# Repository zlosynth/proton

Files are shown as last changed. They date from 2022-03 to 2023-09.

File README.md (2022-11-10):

# Proton

Playground module for eurorack prototyping.

<p align="center">
   Panel illustration
</p>

* This is meant to help to test ideas of new modules before they get their own
  custom hardware.
* This is not meant to be stable or simple.

# Development

See [DEVELOPMENT.md](DEVELOPMENT.md) to find some basic commands to interact
with the project.

# License

Software of Proton is distributed under the terms of the General Public
License version 3. See [LICENSE-SOFTWARE](LICENSE-SOFTWARE) for details.

Schematics and PCB layout are distributed under the terms of Creative Commons
BY-SA. See [LICENSE-HARDWARE](LICENSE-HARDWARE) for details. Parts of the
schematics are based on [Emilie Gillet's Mutable
Instruments](https://github.com/pichenettes/eurorack) and [Electrosmith's
Patch](https://www.electro-smith.com/daisy/patch) kudos to them for making them
open.

# Changelog

Read the [CHANGELOG.md](CHANGELOG.md) to learn about changes introduced in each
release.

# Versioning

See [VERSIONING.md](VERSIONING.md) to find detailed information about versioning
of the project and compatability between its software and hardware.

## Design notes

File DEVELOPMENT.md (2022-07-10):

# Development

## Environment setup

Follow [Rust's installation guide](https://www.rust-lang.org/tools/install).

Install tooling of the embedded Rust target for Cortex-M7F:

```sh
rustup target add thumbv7em-none-eabihf
```

## Formatting, linting, unit tests

Run formatting, linter and unit tests:

```sh
make
```

Read the Makefile to learn more.

## Benchmark

If a package has a benchmark defined, `cd` into its directory and run it via:

``` sh
cargo +nightly bench --bench bench
```

Use the benchmark for profiling:

``` sh
rm -f target/release/deps/bench-*
rm -f callgrind.out.*
RUSTFLAGS="-g" cargo +nightly bench --bench bench --no-run
BENCH=$(find target/release/deps -type f -executable -name 'bench-*')
TEST=instrument
valgrind \
    --tool=callgrind \
    --dump-instr=yes \
    --collect-jumps=yes \
    --simulate-cache=yes \
    ${BENCH} --bench --profile-time 10 ${TEST}
kcachegrind callgrind.out.*
```

## Flash via ST-Link

This requires external probe, such as the ST LINK-V3 MINI. The benefit of this
approach is that it allows to stay connected to the module, read logs, run a
debugger, or execute tests on the module. Note that the module needs to be
powered while the probe is connected.

This project uses [probe-rs](https://github.com/probe-rs/probe-rs) to deal with
flashing. Start by installing its dependencies. For Fedora, it can be done by
running the following:

```sh
sudo dnf install -y libusbx-devel libftdi-devel libudev-devel
```

You may then install needed udev rules. See the [probe-rs getting
started](https://probe.rs/docs/getting-started/probe-setup/) to learn how.

Then install Rust dependencies of probe-rs:

```sh
cargo install probe-run
cargo install flip-link
```

To flash the project, call this make target:

```sh
make flash
```

Logging level can be set using an environment variable:

```sh
DEFMT_LOG=info make flash
```

To flash a release build, set a flag:

```sh
make flash FLAGS="--release"
```

Some tests must be executed directly on the module. To run those, use the
following target:

```sh
make test-embedded
```

## Flash via DFU

Unlike ST-Link, DFU flashing does not require any external probe. Just connect
the module to your computer via a USB cable.

First, install [dfu-util](http://dfu-util.sourceforge.net/). On Fedora, this can
be done by calling:

```sh
sudo dnf install dfu-util
```

To flash the project, call this make target:

```sh
make flash-dfu
```

To flash a release build, extend the command with a flag:

```sh
make flash-dfu FLAGS="--release"
```

## Firmware size

Check firmware size:

```sh
cd eurorack && cargo +nightly size --bin firmware --release -- -m # or -A
```

## Run a debugger

I prefer to use [gdbgui](https://www.gdbgui.com/) when I need to attach a
debugger to a test run.

First, install gdbgui following its [installation
guide](https://www.gdbgui.com/installation/). The make target also requires `jq`
to be installed in the system.

To attach the debugger to a unit test run:

```sh
make debug-test WHAT=ui
```

After the debugger is open, set breakpoints, type `r` into the GDB console and
click Continue.

## Pure data

To try out the project via Pure Data:

```sh
make puredata
```

And more under `hack/` and in the `Makefile`.

## Gerbers, BOM and CPL

I extensivelly use https://github.com/Bouni/kicad-jlcpcb-tools to deal with the
matters listed in the title, and to prepare project for manufacture.

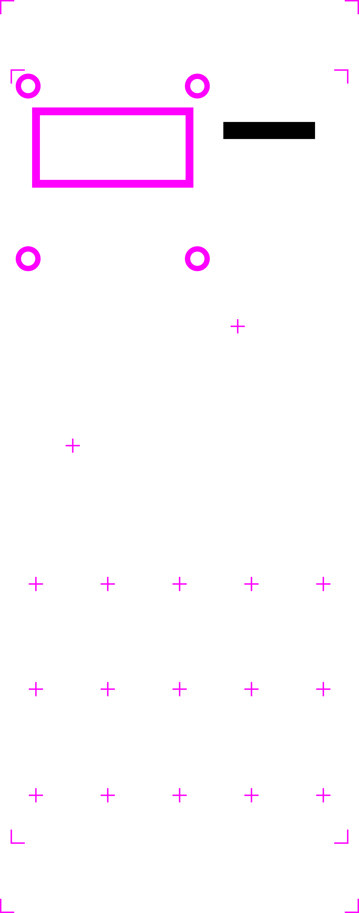
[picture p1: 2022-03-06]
hardware/outlines.png

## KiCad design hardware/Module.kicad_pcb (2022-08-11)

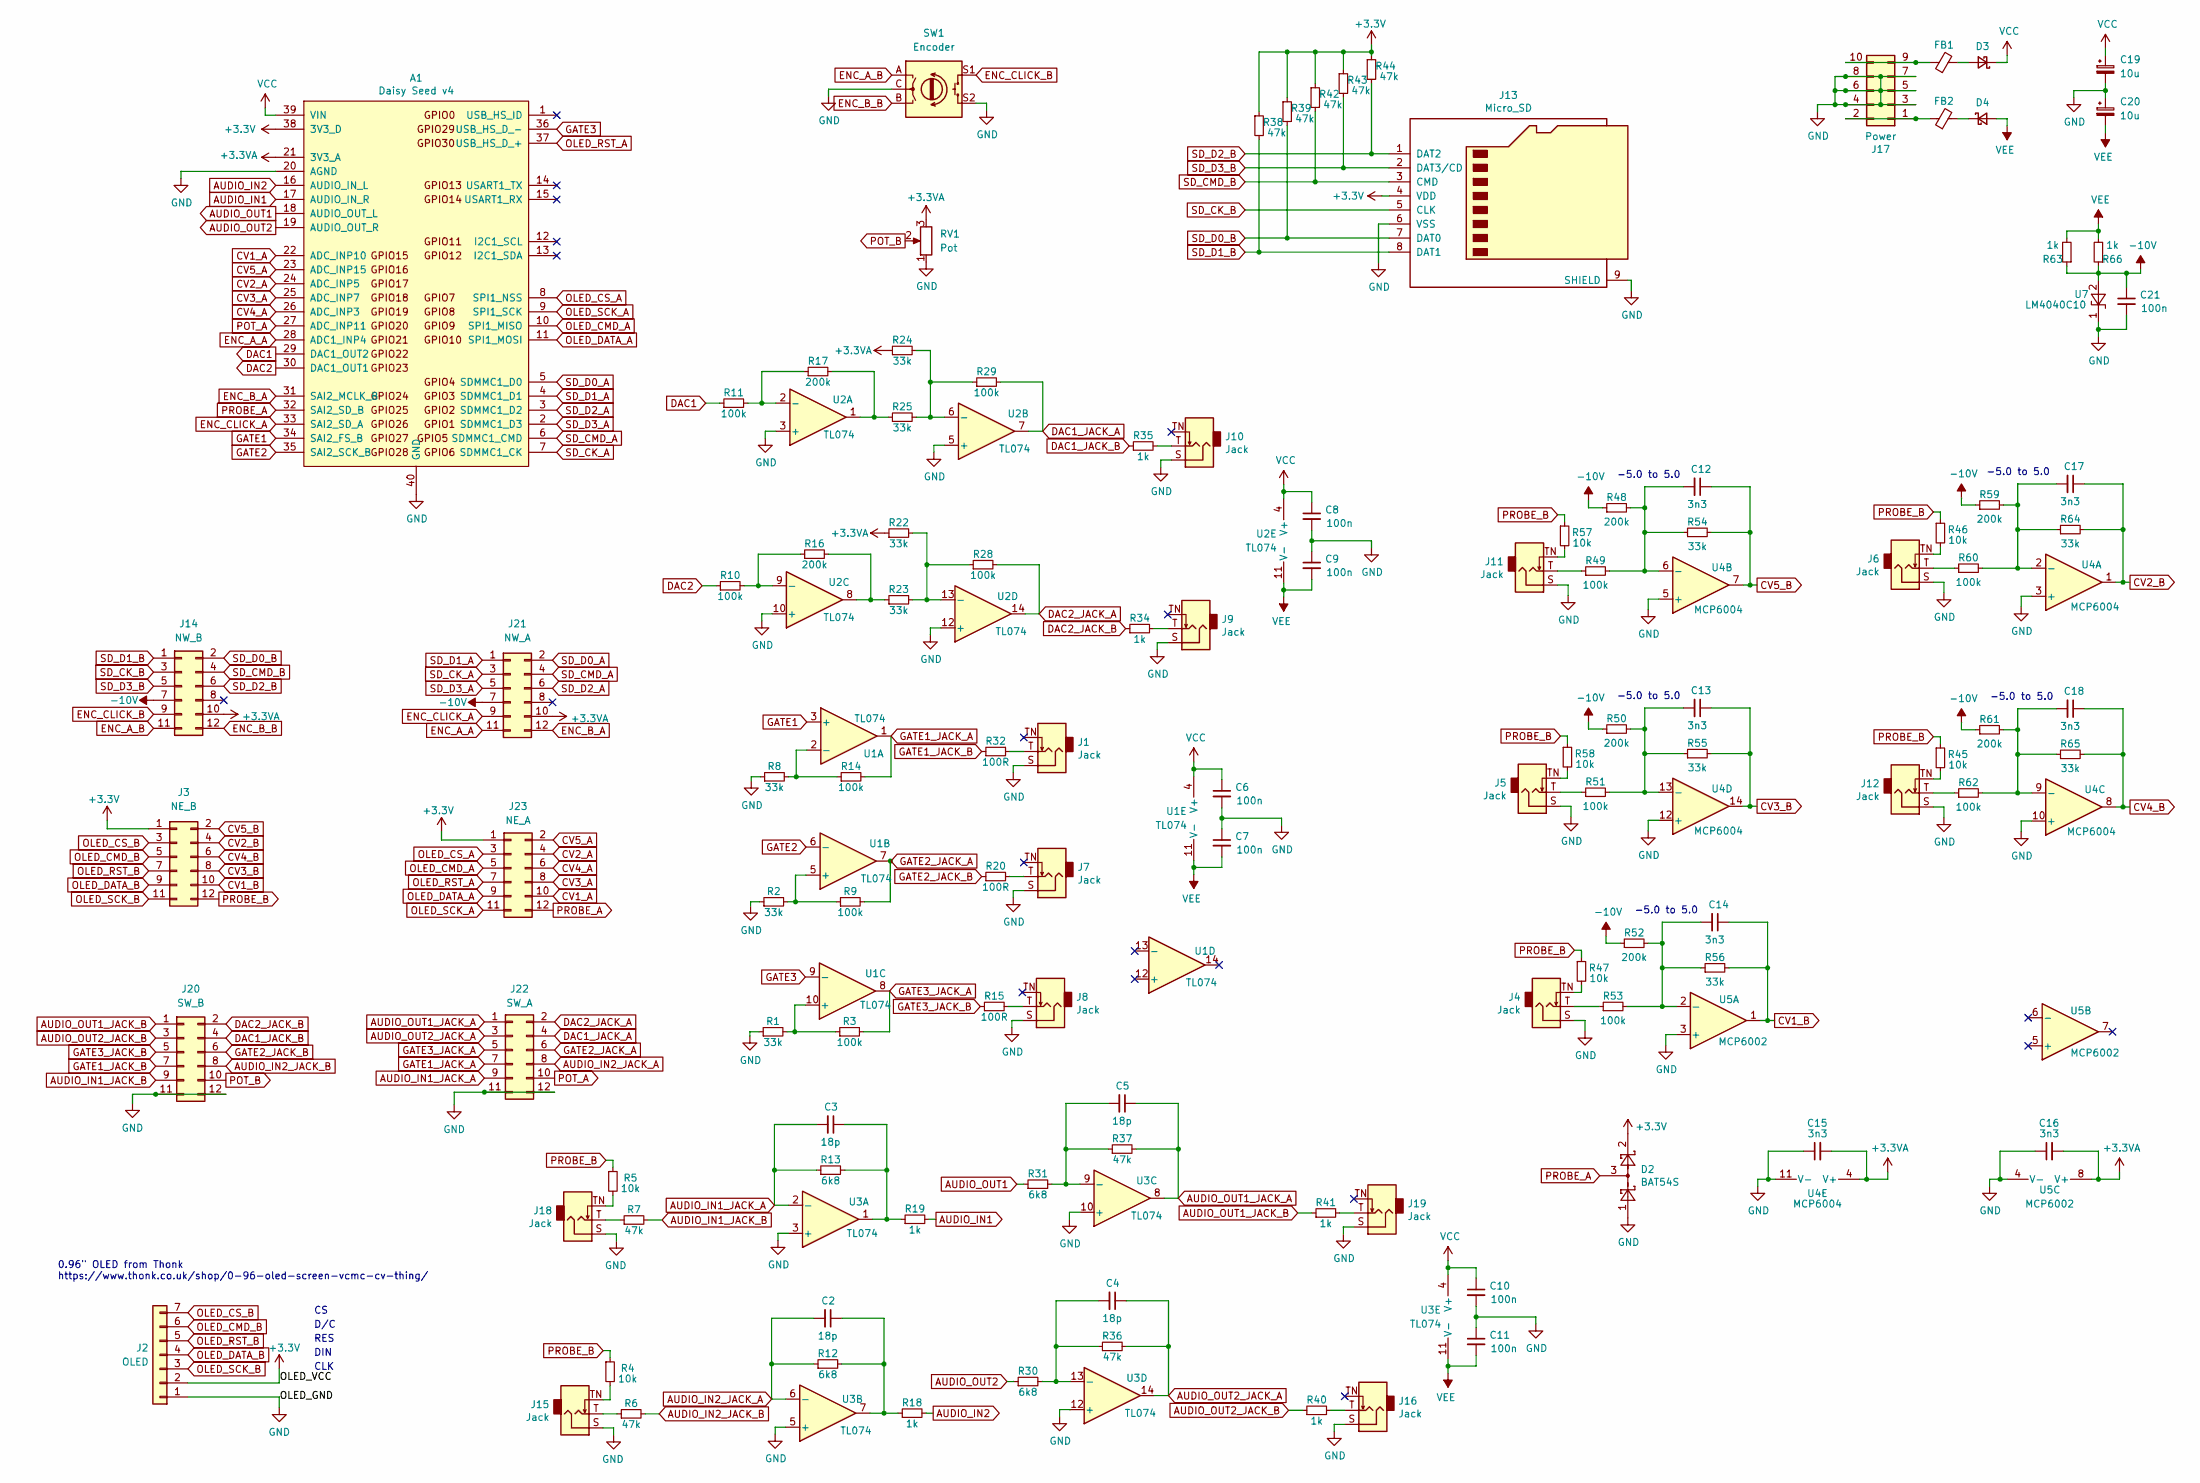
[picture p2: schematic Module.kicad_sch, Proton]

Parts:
A1: Daisy Seed v4; Device_Audio_Electrosmith_Daisy_Seed; Mfr Part Number M20-7822046
C2, C3, C4, C5: 18p; C_0603_1608Metric_Pad1.08x0.95mm_HandSolder; Mfr Part Number CL10C180JB81PNC; LCSC C1647
C6, C7, C8, C9, C10, C11: 100n; C_0603_1608Metric_Pad1.08x0.95mm_HandSolder; Mfr Part Number CL10F104ZO8NNNC; LCSC C14663
C12, C13, C14, C15, C16, C17, C18: 3n3; C_0603_1608Metric_Pad1.08x0.95mm_HandSolder; Mfr Part Number CL10B332KB8NNNC; LCSC C1613
C19, C20: 10u; CP_Elec_6.3x5.8
C21: 100n; C_0603_1608Metric_Pad1.08x0.95mm_HandSolder; Mfr Part Number CL31B104KBCNNNL; LCSC C24497
D2: BAT54S; SOT-23_Handsoldering; Mfr Part Number BAT54S,215
D3, D4: Schottky; D_SOD-123; Mfr Part Number STPS0540ZY; LCSC C8598
FB1, FB2: FB; L_0603_1608Metric_Pad1.05x0.95mm_HandSolder
J1, J4, J5, J6, J7, J8, J9, J10, J11, J12, J15, J16, J18, J19: Jack; Jack_3.5mm_QingPu_WQP-PJ398SM_Vertical_CircularHoles
J2: OLED; PinSocket_1x07_P2.54mm_Vertical
J3: NE_B; PinSocket_2x06_P2.54mm_Vertical
J13: Micro_SD; microsd_connector
J14: NW_B; PinSocket_2x06_P2.54mm_Vertical
J17: Power; PinHeader_2x05_P2.54mm_Vertical; Mfr Part Number 87914-1016
J20: SW_B; PinSocket_2x06_P2.54mm_Vertical
J21: NW_A; PinHeader_2x06_P2.54mm_Vertical
J22: SW_A; PinHeader_2x06_P2.54mm_Vertical
J23: NE_A; PinHeader_2x06_P2.54mm_Vertical
R1, R2, R8, R22, R23, R24, R25: 33k; R_0603_1608Metric_Pad0.98x0.95mm_HandSolder; Mfr Part Number CR0603-JW-682ELF; LCSC C23212
R3, R9, R14, R28, R29: 100k; R_0603_1608Metric_Pad0.98x0.95mm_HandSolder; Mfr Part Number CR0603-FX-4702ELF; LCSC C25819
R4, R5, R45, R46, R47, R57, R58: 10k; R_0603_1608Metric_Pad0.98x0.95mm_HandSolder; Mfr Part Number CR0603-FX-1002ELF; LCSC C25744
R6, R7: 47k; R_0603_1608Metric_Pad0.98x0.95mm_HandSolder; Mfr Part Number CR0603-JW-682ELF; LCSC C23212
R10, R11: 100k; R_0603_1608Metric_Pad0.98x0.95mm_HandSolder; Mfr Part Number CR0603-JW-682ELF; LCSC C23212
R12, R13: 6k8; R_0603_1608Metric_Pad0.98x0.95mm_HandSolder; Mfr Part Number CR0603-FX-4702ELF; LCSC C25819
R15, R20, R32: 100R; R_0603_1608Metric_Pad0.98x0.95mm_HandSolder; Mfr Part Number CR0603-FX-1001ELF; LCSC C21190
R16, R17: 200k; R_0603_1608Metric_Pad0.98x0.95mm_HandSolder; Mfr Part Number CR0603-FX-4702ELF; LCSC C25819
R18, R19, R34, R35, R40, R41, R63, R66: 1k; R_0603_1608Metric_Pad0.98x0.95mm_HandSolder; Mfr Part Number CR0603-FX-1001ELF; LCSC C21190
R30, R31: 6k8; R_0603_1608Metric_Pad0.98x0.95mm_HandSolder; Mfr Part Number CR0603-JW-682ELF; LCSC C23212
R36, R37: 47k; R_0603_1608Metric_Pad0.98x0.95mm_HandSolder; Mfr Part Number CR0603-FX-4702ELF; LCSC C25819
R38, R39, R42, R43, R44: 47k; R_0603_1608Metric_Pad0.98x0.95mm_HandSolder; Mfr Part Number CR0603-FX-1002ELF; LCSC C25744
R48: 200k; R_0603_1608Metric_Pad0.98x0.95mm_HandSolder; Mfr Part Number CR0603-FX-1803ELF; LCSC C25808
R49, R51, R53, R60, R62: 100k; R_0603_1608Metric_Pad0.98x0.95mm_HandSolder; Mfr Part Number CR0603-JW-104ELF; LCSC C25803
R50: 200k; R_0603_1608Metric_Pad0.98x0.95mm_HandSolder; Mfr Part Number CR0603-FX-1203ELF; LCSC C22827
R52, R61: 200k; R_0603_1608Metric_Pad0.98x0.95mm_HandSolder; Mfr Part Number CR0603-FX-1203ELF; LCSC C25808
R54: 33k; R_0603_1608Metric_Pad0.98x0.95mm_HandSolder; Mfr Part Number CR0603-FX-4702ELF; LCSC C4184
R55: 33k; R_0603_1608Metric_Pad0.98x0.95mm_HandSolder; Mfr Part Number CR0603-FX-2002ELF; LCSC C25819
R56, R65: 33k; R_0603_1608Metric_Pad0.98x0.95mm_HandSolder; Mfr Part Number CR0603-FX-2002ELF; LCSC C4184
R59: 200k; R_0603_1608Metric_Pad0.98x0.95mm_HandSolder; Mfr Part Number CR0603-FX-1803ELF; LCSC C22827
R64: 33k; R_0603_1608Metric_Pad0.98x0.95mm_HandSolder; Mfr Part Number CR0603-FX-4702ELF; LCSC C25819
RV1: Pot; Potentiometer_Alpha_RD901F-40-00D_Single_Vertical
SW1: Encoder; RotaryEncoder_Alps_EC11E-Switch_Vertical_H20mm
U1, U2, U3: TL074; SOIC-14_3.9x8.7mm_P1.27mm
U4: MCP6004; SOIC-14_3.9x8.7mm_P1.27mm
U5: MCP6002; SOIC-8_3.9x4.9mm_P1.27mm; Mfr Part Number MCP6002-I/SN; LCSC C7377
U7: LM4040C10; SOT-23_Handsoldering; Mfr Part Number LM4040C10IDBZR; LCSC C201738

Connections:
+3.3VA: A1.21 (3V3_A), C15.2, C16.2, J14.10, J21.10, R22.1, R24.1, RV1.3, U4.4 (V+), U5.8 (V+)
+3V3: A1.38 (3V3_D), D2.2, J2.2, J3.1, J13.4 (VDD), J23.1, R38.1, R39.1, R42.1, R43.1, R44.1
-10V: C21.1, J14.7, J21.7, R48.1, R50.1, R52.1, R59.1, R61.1, R63.1, R66.1, U7.2 (A)
AUDIO_IN1: A1.17 (AUDIO_IN_R), R19.2
AUDIO_IN1_JACK_A: C3.2, J22.9, R13.1, U3.2 (-)
AUDIO_IN1_JACK_B: J20.9, R7.2
AUDIO_IN2: A1.16 (AUDIO_IN_L), R18.2
AUDIO_IN2_JACK_A: C2.2, J22.8, R12.1, U3.6 (-)
AUDIO_IN2_JACK_B: J20.8, R6.2
AUDIO_OUT1: A1.18 (AUDIO_OUT_L), R31.1
AUDIO_OUT1_JACK_A: C5.1, J22.1, R37.2, U3.8
AUDIO_OUT1_JACK_B: J20.1, R41.1
AUDIO_OUT2: A1.19 (AUDIO_OUT_R), R30.1
AUDIO_OUT2_JACK_A: C4.1, J22.3, R36.2, U3.14
AUDIO_OUT2_JACK_B: J20.3, R40.1
CV1_A: A1.22 (ADC_INP10), J23.10
CV1_B: C14.1, J3.10, R56.2, U5.1
CV2_A: A1.24 (ADC_INP5), J23.4
CV2_B: C17.1, J3.4, R64.2, U4.1
CV3_A: A1.25 (ADC_INP7), J23.8
CV3_B: C13.1, J3.8, R55.2, U4.14
CV4_A: A1.26 (ADC_INP3), J23.6
CV4_B: C18.1, J3.6, R65.2, U4.8
CV5_A: A1.23 (ADC_INP15), J23.2
CV5_B: C12.1, J3.2, R54.2, U4.7
DAC1: A1.29 (DAC1_OUT2), R11.1
DAC1_JACK_A: J22.4, R29.2, U2.7
DAC1_JACK_B: J20.4, R35.1
DAC2: A1.30 (DAC1_OUT1), R10.1
DAC2_JACK_A: J22.2, R28.2, U2.14
DAC2_JACK_B: J20.2, R34.1
ENC_A_A: A1.28 (ADC1_INP4), J21.11
ENC_A_B: J14.11, SW1.A
ENC_B_A: A1.31 (SAI2_MCLK_B), J21.12
ENC_B_B: J14.12, SW1.B
ENC_CLICK_A: A1.33 (SAI2_SD_A), J21.9
ENC_CLICK_B: J14.9, SW1.S1
GATE1: A1.34 (SAI2_FS_B), U1.3 (+)
GATE1_JACK_A: J22.7, R14.2, U1.1
GATE1_JACK_B: J20.7, R32.1
GATE2: A1.35 (SAI2_SCK_B), U1.6 (-)
GATE2_JACK_A: J22.6, R9.2, U1.7
GATE2_JACK_B: J20.6, R20.1
GATE3: A1.36 (USB_HS_D_-), U1.9 (-)
GATE3_JACK_A: J22.5, R3.2, U1.8
GATE3_JACK_B: J20.5, R15.1
GND: A1.20 (AGND), A1.40 (GND), C6.2, C7.1, C8.2, C9.1, C10.2, C11.1, C15.1, C16.1, C19.2, C20.1, C21.2, D2.1, J1.S, J2.1, J4.S, J5.S, J6.S, J7.S, J8.S, J9.S, J10.S, J11.S, J12.S, J13.6 (VSS), J13.9 (SHIELD), J15.S, J16.S, J17.3, J17.4, J17.5, J17.6, J17.7, J17.8, J18.S, J19.S, J20.11, J20.12, J22.11, J22.12, R1.1, R2.1, R8.1, RV1.1, SW1.C, SW1.S2, U2.3 (+), U2.5 (+), U2.10 (+), U2.12 (+), U3.3 (+), U3.5 (+), U3.10 (+), U3.12 (+), U4.3 (+), U4.5 (+), U4.10 (+), U4.11 (V-), U4.12 (+), U5.3 (+), U5.4 (V-), U7.1 (K)
unnamed: C2.1, R12.2, R18.1, U3.7
unnamed: C3.1, R13.2, R19.1, U3.1
unnamed: C4.2, R30.2, R36.1, U3.13 (-)
unnamed: C5.2, R31.2, R37.1, U3.9 (-)
unnamed: C12.2, R48.2, R49.2, R54.1, U4.6 (-)
unnamed: C13.2, R50.2, R51.2, R55.1, U4.13 (-)
unnamed: C14.2, R52.2, R53.2, R56.1, U5.2 (-)
unnamed: C17.2, R59.2, R60.2, R64.1, U4.2 (-)
unnamed: C18.2, R61.2, R62.2, R65.1, U4.9 (-)
unnamed: D3.2 (A), FB1.2
unnamed: D4.1 (K), FB2.2
unnamed: FB1.1, J17.9, J17.10
unnamed: FB2.1, J17.1, J17.2
unnamed: J1.T, R32.2
unnamed: J4.T, R53.1
unnamed: J4.TN, R47.2
unnamed: J5.T, R51.1
unnamed: J5.TN, R58.2
unnamed: J6.T, R60.1
unnamed: J6.TN, R46.2
unnamed: J7.T, R20.2
unnamed: J8.T, R15.2
unnamed: J9.T, R34.2
unnamed: J10.T, R35.2
unnamed: J11.T, R49.1
unnamed: J11.TN, R57.2
unnamed: J12.T, R62.1
unnamed: J12.TN, R45.2
unnamed: J15.T, R6.1
unnamed: J15.TN, R4.2
unnamed: J16.T, R40.2
unnamed: J18.T, R7.1
unnamed: J18.TN, R5.2
unnamed: J19.T, R41.2
unnamed: R1.2, R3.1, U1.10 (+)
unnamed: R2.2, R9.1, U1.5 (+)
unnamed: R10.2, R16.1, U2.9 (-)
unnamed: R11.2, R17.1, U2.2 (-)
unnamed: R8.2, R14.1, U1.2 (-)
unnamed: R16.2, R23.1, U2.8
unnamed: R17.2, R25.1, U2.1
unnamed: R22.2, R23.2, R28.1, U2.13 (-)
unnamed: R24.2, R25.2, R29.1, U2.6 (-)
OLED_CMD_A: A1.10 (SPI1_MISO), J23.5
OLED_CMD_B: J2.6, J3.5
OLED_CS_A: A1.8 (SPI1_NSS), J23.3
OLED_CS_B: J2.7, J3.3
OLED_DATA_A: A1.11 (SPI1_MOSI), J23.9
OLED_DATA_B: J2.4, J3.9
OLED_RST_A: A1.37 (USB_HS_D_+), J23.7
OLED_RST_B: J2.5, J3.7
OLED_SCK_A: A1.9 (SPI1_SCK), J23.11
OLED_SCK_B: J2.3, J3.11
POT_A: A1.27 (ADC_INP11), J22.10
POT_B: J20.10, RV1.2
PROBE_A: A1.32 (SAI2_SD_B), D2.3, J23.12
PROBE_B: J3.12, R4.1, R5.1, R45.1, R46.1, R47.1, R57.1, R58.1
SD_CK_A: A1.7 (SDMMC1_CK), J21.3
SD_CK_B: J13.5 (CLK), J14.3
SD_CMD_A: A1.6 (SDMMC1_CMD), J21.4
SD_CMD_B: J13.3 (CMD), J14.4, R42.2
SD_D0_A: A1.5 (SDMMC1_D0), J21.2
SD_D0_B: J13.7 (DAT0), J14.2, R39.2
SD_D1_A: A1.4 (SDMMC1_D1), J21.1
SD_D1_B: J13.8 (DAT1), J14.1, R38.2
SD_D2_A: A1.3 (SDMMC1_D2), J21.6
SD_D2_B: J13.1 (DAT2), J14.6, R44.2
SD_D3_A: A1.2 (SDMMC1_D3), J21.5
SD_D3_B: J13.2 (DAT3/CD), J14.5, R43.2
VCC: A1.39 (VIN), C6.1, C8.1, C10.1, C19.1, D3.1 (K), U1.4 (V+), U2.4 (V+), U3.4 (V+)
VEE: C7.2, C9.2, C11.2, C20.2, D4.2 (A), R63.2, R66.2, U1.11 (V-), U2.11 (V-), U3.11 (V-)

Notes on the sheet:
-5.0 to 5.0
0.96" OLED from Thonk https://www.thonk.co.uk/shop/0-96-oled-screen-vcmc-cv-thing/
CLK
RES
DIN
D/C

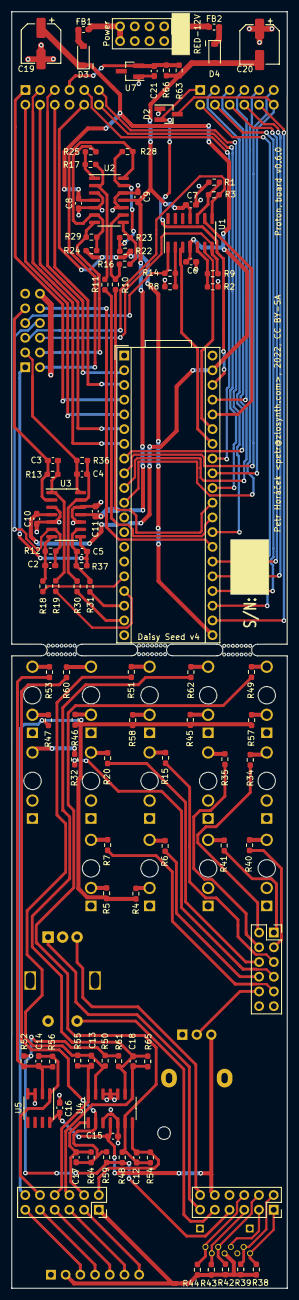
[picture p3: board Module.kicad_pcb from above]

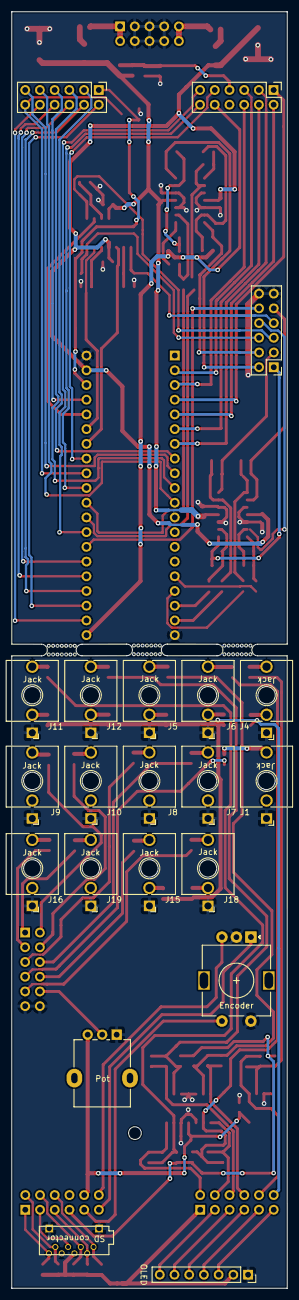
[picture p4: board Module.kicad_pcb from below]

Board: 2 copper layers, 47.6 x 220.4 mm, 122 parts (21 on the bottom side), 118 nets.

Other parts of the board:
mouse-bite-2mm-slot, mouse-bite-2mm-slot#2, mouse-bite-2mm-slot#3: VAL**; mouse-bite-2mm-slot

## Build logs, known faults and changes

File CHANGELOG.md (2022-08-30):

# Changelog

All notable changes to this project will be documented in this file. See
[VERSIONING.md](VERSIONING.md) for more information about versioning and
backwards compatibility.

## Unreleased

* Known issue: Gate 2 and 3 have reversed output of -10 V.
* Replace one of the encoders with a pot.
* Adjust encoder abstraction to the new hardware.
* Implement gate output.
* Implement CV output.
* Introduce binding to Kaseta.
* Process input audio.
* Remove global allocator.
* Remove karplus strong.
* Switch to stable Rust.

## 0.6.0

* Transform the module into two-board design.
* Remove MIDI input and output.
* Implement a basic tape simulation instrument.
* Introduce oversampling converters over the Signal trait.
* Reconcile CV inputs and pass them to instruments.
* Allow control of cutoff and feedback of karplus strong via CV.

## 0.5.0

* Implement sound output in the firmware.
* Introduce a basic instrument based around Karplus Strong algorithm.
* Allow custom settings for f32 attribute range.
* Implement a simple turing machine-like sequencer.

## 0.4.0

* Integrate display in the firmware.
* Use left encoder to move through attributes.
* Use right encoder to adjust attributes.

## 0.3.0

* Introduce support for module instantiation and removal.
* Implement menu for dynamic connecting and disconnecting of patches.

## 0.2.0

* Introduce signal buffer abstraction.
* Abstract cells used to access internal audio output and control input data.
* Implement read-only UI for 128x64 OLED displays.

## 0.1.0

* Initialize the project with READMEs and licensing.
* Add schetch of the front panel.
* Prepare schematics of the module.
* Design the PCB of the module.
* Implement basic saw oscillator.
* Introduce pure data external for testing.

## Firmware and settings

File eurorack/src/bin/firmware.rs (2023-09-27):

#![no_main]
#![no_std]

use proton_eurorack as _; // global logger + panicking-behavior

#[rtic::app(device = stm32h7xx_hal::pac, peripherals = true, dispatchers = [EXTI0, EXTI1, EXTI2])]
mod app {
    use core::mem::MaybeUninit;

    use fugit::ExtU64;
    use heapless::spsc::{Consumer, Producer, Queue};
    use systick_monotonic::Systick;

    use daisy::led::LedUser;
    use hal::adc::{Adc, Enabled};
    use hal::pac::{ADC1, ADC2};
    use stm32h7xx_hal as hal;

    #[cfg(feature = "traky")]
    use proton_instruments_traky::Instrument;

    use proton_control::input_snapshot::InputSnapshot;
    use proton_eurorack::system::audio::{Audio, SAMPLE_RATE};
    use proton_eurorack::system::display::Display;
    use proton_eurorack::system::randomizer::Randomizer;
    use proton_eurorack::system::System;
    use proton_instruments_interface::{Instrument as _, MemoryManager};
    use proton_ui::action::Action as InputAction;
    use proton_ui::display::draw as draw_view_on_display;
    use proton_ui::reaction::Reaction as InputReaction;
    use proton_ui::reducer;
    use proton_ui::state::State;
    use proton_ui::view::View;

    type UserInput = proton_ui::input::Input<
        proton_eurorack::system::encoder::EncoderRotaryPinA,
        proton_eurorack::system::encoder::EncoderRotaryPinB,
        proton_eurorack::system::encoder::EncoderButtonPin,
    >;

    type ControlInput = proton_control::input_processor::InputProcessor<
        Adc<ADC1, Enabled>,
        Adc<ADC2, Enabled>,
        proton_eurorack::system::cv_input::Pot,
        proton_eurorack::system::cv_input::CvInput1,
        proton_eurorack::system::cv_input::CvInput2,
        proton_eurorack::system::cv_input::CvInput3,
        proton_eurorack::system::cv_input::CvInput4,
        proton_eurorack::system::cv_input::CvInput5,
    >;

    type ControlOutput = proton_control::output_processor::OutputProcessor<
        proton_eurorack::system::gate_output::GateOutput1,
        proton_eurorack::system::gate_output::GateOutput2,
        proton_eurorack::system::gate_output::GateOutput3,
        proton_eurorack::system::cv_output::CvOutput1,
        proton_eurorack::system::cv_output::CvOutput2,
    >;

    #[monotonic(binds = SysTick, default = true)]
    type Mono = Systick<1000>; // 1 kHz / 1 ms granularity

    #[shared]
    struct Shared {}

    #[local]
    struct Local {
        audio: Audio,
        randomizer: Randomizer,
        instrument: Instrument,
        led: LedUser,
        user_input: UserInput,
        control_input: ControlInput,
        _control_output: ControlOutput,
        display: Display,
        state: State,
        input_actions_producer: Producer<'static, InputAction, 6>,
        input_actions_consumer: Consumer<'static, InputAction, 6>,
        input_reactions_producer: Producer<'static, InputReaction, 6>,
        input_reactions_consumer: Consumer<'static, InputReaction, 6>,
        control_input_producer: Producer<'static, InputSnapshot, 6>,
        control_input_consumer: Consumer<'static, InputSnapshot, 6>,
    }

    #[init(
        local = [
            input_actions_queue: Queue<InputAction, 6> = Queue::new(),
            input_reactions_queue: Queue<InputReaction, 6> = Queue::new(),
            control_input_queue: Queue<InputSnapshot, 6> = Queue::new(),
        ]
    )]
    fn init(cx: init::Context) -> (Shared, Local, init::Monotonics) {
        defmt::info!("INIT");

        let (input_actions_producer, input_actions_consumer) = cx.local.input_actions_queue.split();
        let (input_reactions_producer, input_reactions_consumer) =
            cx.local.input_reactions_queue.split();
        let (control_input_producer, control_input_consumer) = cx.local.control_input_queue.split();

        let system = System::init(cx.core, cx.device);

        let display = system.display;
        let led = system.led;
        let mono = system.mono;
        let sdram = system.sdram;
        let randomizer = system.randomizer;
        let mut audio = system.audio;
        audio.spawn();

        let user_input = UserInput::new(system.button, system.rotary);

        let control_input = ControlInput::new(
            system.adc_1,
            system.adc_2,
            system.pot,
            system.cv_input_1,
            system.cv_input_2,
            system.cv_input_3,
            system.cv_input_4,
            system.cv_input_5,
        );

        let control_output = ControlOutput::new(
            system.gate_1,
            system.gate_2,
            system.gate_3,
            system.cv_output_1,
            system.cv_output_2,
        );

        let instrument = {
            let mut memory_manager = {
                let ram_slice = unsafe {
                    let ram_items = sdram.size() / core::mem::size_of::<MaybeUninit<u32>>();
                    let ram_ptr = sdram.base_address as *mut MaybeUninit<u32>;
                    core::slice::from_raw_parts_mut(ram_ptr, ram_items)
                };
                MemoryManager::from(ram_slice)
            };
            Instrument::new(
                SAMPLE_RATE,
                &mut memory_manager,
                &mut system.sdmmc.sdmmc_block_device(),
            )
        };
        let state = instrument.state();
        #[allow(clippy::needless_borrow)] // It's not needless, it fails without it
        let view: View = (&state).into();

        update_display::spawn(view).ok().unwrap();
        toggle_indicator::spawn().unwrap();
        read_user_controls::spawn().unwrap();
        read_control_input::spawn().unwrap();
        update_state::spawn().unwrap();

        (
            Shared {},
            Local {
                audio,
                randomizer,
                instrument,
                led,
                user_input,
                control_input,
                _control_output: control_output,
                display,
                state,
                input_actions_producer,
                input_actions_consumer,
                input_reactions_producer,
                input_reactions_consumer,
                control_input_producer,
                control_input_consumer,
            },
            init::Monotonics(mono),
        )
    }

    #[task(binds = DMA1_STR1, local = [input_reactions_consumer, control_input_consumer, randomizer, instrument, audio], priority = 4)]
    fn handle_dsp(cx: handle_dsp::Context) {
        use core::convert::TryInto;

        let input_reactions_consumer = cx.local.input_reactions_consumer;
        let control_input_consumer = cx.local.control_input_consumer;
        let instrument = cx.local.instrument;
        let randomizer = cx.local.randomizer;
        let audio = cx.local.audio;

        while let Some(control_snapshot) = control_input_consumer.dequeue() {
            instrument.update_control(control_snapshot);
        }

        while let Some(action) = input_reactions_consumer.dequeue() {
            let reaction = action.try_into();
            instrument.execute(reaction.unwrap());
        }

        audio.update_buffer(|buffer| {
            instrument.process(&mut buffer[..], randomizer);
        });
    }

    #[task(local = [user_input, input_actions_producer], priority = 3)]
    fn read_user_controls(cx: read_user_controls::Context) {
        let user_input = cx.local.user_input;
        let input_actions_producer = cx.local.input_actions_producer;

        for action in user_input.process() {
            let _ = input_actions_producer.enqueue(action);
        }

        read_user_controls::spawn_after(1.millis()).unwrap();
    }

    #[task(local = [control_input, control_input_producer], priority = 2)]
    fn read_control_input(cx: read_control_input::Context) {
        let control_input = cx.local.control_input;
        let control_input_producer = cx.local.control_input_producer;

        control_input_producer
            .enqueue(control_input.update())
            .ok()
            .unwrap();

        read_control_input::spawn_after(1.millis()).unwrap();
    }

    #[task(local = [input_actions_consumer, input_reactions_producer, state])]
    fn update_state(cx: update_state::Context) {
        let input_actions_consumer = cx.local.input_actions_consumer;
        let input_reactions_producer = cx.local.input_reactions_producer;

        let state = cx.local.state;

        while let Some(action) = input_actions_consumer.dequeue() {
            let reaction = reducer::reduce(action, state);
            if let Some(reaction) = reaction {
                #[allow(clippy::ok_expect)]
                input_reactions_producer
                    .enqueue(reaction)
                    .ok()
                    .expect("the queue is full");
            }
        }

        #[allow(clippy::needless_borrow)] // It's not needless, it fails without it
        let view = (&*state).into();
        update_display::spawn(view).ok().unwrap();

        update_state::spawn_after(1.millis()).unwrap();
    }

    #[task(local = [display])]
    fn update_display(cx: update_display::Context, view: View) {
        let display = cx.local.display;
        draw_view_on_display(display, &view).unwrap();
        display.flush().unwrap();
    }

    #[task(local = [led])]
    fn toggle_indicator(cx: toggle_indicator::Context) {
        cx.local.led.toggle();
        toggle_indicator::spawn_after(1.secs()).unwrap();
    }
}

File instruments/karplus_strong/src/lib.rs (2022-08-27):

#![no_std]

#[allow(unused_imports)]
use micromath::F32Ext;

use core::convert::TryFrom;
use core::fmt;

use heapless::FnvIndexMap as IndexMap;
use heapless::Vec;

use proton_control::input_snapshot::InputSnapshot;
use proton_primitives::ad_envelope::{Ad, Config as AdConfig};
use proton_primitives::ring_buffer::RingBuffer;
use proton_primitives::state_variable_filter::{Bandform, StateVariableFilter};
use proton_primitives::white_noise::WhiteNoise;
use proton_ui::reaction::Reaction;
use proton_ui::state::*;

const NAME: &str = "Karplus Strong";

const CUTOFF_ATTRIBUTE: &str = "cutoff";
const CUTOFF_DEFAULT: f32 = 1000.0;

const FEEDBACK_ATTRIBUTE: &str = "feedback";
const FEEDBACK_DEFAULT: f32 = 0.95;

const DENSITY_ATTRIBUTE: &str = "density";
const DENSITY_DEFAULT: f32 = 4.0;

const CHANGE_ATTRIBUTE: &str = "change";
const CHANGE_DEFAULT: f32 = 1.0;

const BEATS_ATTRIBUTE: &str = "beats";
const BEATS_DEFAULT: f32 = 4.0;

const OFF_ON: [&str; 2] = ["off", "on"];
const WHOLE_ATTRIBUTE: &str = "whole";
const WHOLE_DEFAULT: usize = 0;
const HALF_TRIPLET_ATTRIBUTE: &str = "half triplet";
const HALF_TRIPLET_DEFAULT: usize = 0;
const HALF_ATTRIBUTE: &str = "half";
const HALF_DEFAULT: usize = 0;
const QUARTER_TRIPLET_ATTRIBUTE: &str = "quarter triplet";
const QUARTER_TRIPLET_DEFAULT: usize = 0;
const QUARTER_ATTRIBUTE: &str = "quarter";
const QUARTER_DEFAULT: usize = 1;
const EIGHT_TRIPLET_ATTRIBUTE: &str = "eight triplet";
const EIGHT_TRIPLET_DEFAULT: usize = 0;
const EIGHT_ATTRIBUTE: &str = "eight";
const EIGHT_DEFAULT: usize = 0;

const MAX_SAMPLE_RATE: u32 = 48_000;
const MIN_FREQUENCY: f32 = 10.0;
const SAMPLES: usize = (MAX_SAMPLE_RATE as f32 / MIN_FREQUENCY) as usize;

const A: f32 = 12.978_271;

pub trait Rand {
    fn generate(&mut self) -> u16;
}

pub struct Instrument {
    svf: StateVariableFilter,
    noise: WhiteNoise,
    envelope: Ad,
    ring_buffer: RingBuffer<SAMPLES>,
    turing: Turing,
    cutoff_ui: f32,
    cutoff_cv: f32,
    feedback_ui: f32,
    feedback_cv: f32,
    frequency: f32,
    sample_rate: u32,
}

fn int_writter(destination: &mut dyn fmt::Write, value: f32) {
    write!(destination, "{:.0}", value).unwrap();
}

fn f3_writter(destination: &mut dyn fmt::Write, value: f32) {
    write!(destination, "{:.3}", value).unwrap();
}

impl Instrument {
    pub fn state(&self) -> State {
        State::new(NAME)
            .with_attributes(&[
                Attribute::new(CUTOFF_ATTRIBUTE).with_value_f32(
                    ValueF32::new(CUTOFF_DEFAULT)
                        .with_min(50.0)
                        .with_max(10000.0)
                        .with_step(10.0)
                        .with_writter(int_writter),
                ),
                Attribute::new(FEEDBACK_ATTRIBUTE).with_value_f32(
                    ValueF32::new(FEEDBACK_DEFAULT)
                        .with_min(0.6)
                        .with_max(1.0)
                        .with_step(0.005)
                        .with_writter(f3_writter),
                ),
                Attribute::new(DENSITY_ATTRIBUTE).with_value_f32(
                    ValueF32::new(DENSITY_DEFAULT)
                        .with_min(0.0)
                        .with_max(16.0)
                        .with_step(1.0)
                        .with_writter(int_writter),
                ),
                Attribute::new(CHANGE_ATTRIBUTE).with_value_f32(
                    ValueF32::new(CHANGE_DEFAULT)
                        .with_min(0.0)
                        .with_max(4.0)
                        .with_step(1.0)
                        .with_writter(int_writter),
                ),
                Attribute::new(BEATS_ATTRIBUTE).with_value_f32(
                    ValueF32::new(BEATS_DEFAULT)
                        .with_min(1.0)
                        .with_max(16.0)
                        .with_step(1.0)
                        .with_writter(int_writter),
                ),
                Attribute::new(WHOLE_ATTRIBUTE).with_value_select(
                    ValueSelect::new(&OFF_ON)
                        .unwrap()
                        .with_selected(WHOLE_DEFAULT),
                ),
                Attribute::new(HALF_TRIPLET_ATTRIBUTE).with_value_select(
                    ValueSelect::new(&OFF_ON)
                        .unwrap()
                        .with_selected(HALF_TRIPLET_DEFAULT),
                ),
                Attribute::new(HALF_ATTRIBUTE).with_value_select(
                    ValueSelect::new(&OFF_ON)
                        .unwrap()
                        .with_selected(HALF_DEFAULT),
                ),
                Attribute::new(QUARTER_TRIPLET_ATTRIBUTE).with_value_select(
                    ValueSelect::new(&OFF_ON)
                        .unwrap()
                        .with_selected(QUARTER_TRIPLET_DEFAULT),
                ),
                Attribute::new(QUARTER_ATTRIBUTE).with_value_select(
                    ValueSelect::new(&OFF_ON)
                        .unwrap()
                        .with_selected(QUARTER_DEFAULT),
                ),
                Attribute::new(EIGHT_TRIPLET_ATTRIBUTE).with_value_select(
                    ValueSelect::new(&OFF_ON)
                        .unwrap()
                        .with_selected(EIGHT_TRIPLET_DEFAULT),
                ),
                Attribute::new(EIGHT_ATTRIBUTE).with_value_select(
                    ValueSelect::new(&OFF_ON)
                        .unwrap()
                        .with_selected(EIGHT_DEFAULT),
                ),
            ])
            .unwrap()
    }

    pub fn new(sample_rate: u32) -> Self {
        assert!(
            sample_rate <= MAX_SAMPLE_RATE,
            "maximum supported sample rate is 48 kHz"
        );

        let svf = {
            let mut svf = StateVariableFilter::new(sample_rate);
            svf.set_bandform(Bandform::LowPass)
                .set_frequency(CUTOFF_DEFAULT);
            svf
        };
        let noise = WhiteNoise::new();
        let envelope = Ad::new(sample_rate as f32);
        let ring_buffer = RingBuffer::new();
        let turing = {
            let mut turing = Turing::new(sample_rate);
            turing.density = DENSITY_DEFAULT as u32;
            turing.rate_of_change = CHANGE_DEFAULT;
            turing.beats = BEATS_DEFAULT as u32;
            turing.lengths.push(NoteLength::Quarter).unwrap();
            turing
        };

        Self {
            svf,
            noise,
            envelope,
            ring_buffer,
            turing,
            feedback_ui: FEEDBACK_DEFAULT,
            feedback_cv: 0.0,
            cutoff_ui: CUTOFF_DEFAULT,
            cutoff_cv: 0.0,
            frequency: 1000.0,
            sample_rate,
        }
    }
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

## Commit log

2022-02-27 Initialize the hardware with Achordion
    [Module.kicad_pcb, Module.sch]
2022-03-02 Prepare the schematic
    [Module.kicad_pcb, Module.sch]
2022-03-02 Add SD card footprint
    [Module.kicad_pcb, Module.sch]
2022-03-02 Update changelog with added schematics
2022-03-06 Design the PCB
    [Module.kicad_pcb, Module.sch]
2022-03-06 Remove a leftover dot on PCB
    [Module.kicad_pcb]
2022-03-06 Remove unused panelization footprints
2022-03-06 Remove misleading label
    [Module.kicad_pcb]
2022-04-29 Update to KiCad 6
    [Module.kicad_pcb, Module.kicad_sch, Module.sch]
2022-04-30 Implement puredata binding for testing
    [lib.rs]
2022-05-01 Integrate encoder scroll action into puredata
2022-05-01 model: Allow switching between views
2022-05-02 Release version 0.2.0
    [Module.kicad_pcb, Module.kicad_sch]
2022-05-06 hw: Describe issues with OLED mapping
    [Module.kicad_sch]
2022-05-07 Switch to module adding when both clicked
2022-05-08 Release version 0.3.0
    [Module.kicad_pcb, Module.kicad_sch]
2022-05-21 Replace plot_pcb with plot_assembly
    Gerbers are now rendered with JLC extensions.
2022-05-21 Make value labels on assembly plan visible
    [Module.kicad_pcb]
2022-05-22 Implement abstraction for rotary encoder
2022-05-22 Update rotary method to sample
2022-05-22 Implement button abstraction
2022-05-22 Use buttons in the firmware
2022-05-22 Implement abstraction of an encoder
2022-05-22 Control instrument via encoders
    This shows that the instrument is not viable here. It does not implement
    Send and sharing display, control input queue and audio in one entity
    would not fly.
2022-05-22 Move encoder types into a separate module
2022-05-22 Use encoder button in display test
2022-05-22 Introduce encoder integration tests
2022-05-24 Implement new UI showing attributes
    This one is made simpler and the data model should be ready for
    multi-threaded model.
2022-05-26 Use left encoder to move through attributes
2022-05-27 Recover from corrupted encoder state
2022-05-27 Implement setting of f32 values through encoder
2022-05-27 Always reset display before drawing
    This makes sure fragment don't stay on the screen between changes.
    [display.rs]
2022-05-27 Switch puredata to use the new ui
2022-05-27 Introduce state variable filter module
2022-05-28 Prototype a karplus strong synth box
2022-05-28 Fix Actions CI by switching to nightly
2022-05-28 Release version 0.4.0
    [Module.kicad_pcb, Module.kicad_sch]
2022-05-28 Add noise generator to karplus strong
    [lib.rs]
2022-05-28 Use compatible noise from DASP library
    [lib.rs]
2022-05-28 Wire up firmware audio
2022-05-28 Shorten the name of karplus strong
    [firmware.rs, lib.rs]
2022-05-28 Use format! to print f32 attributes
    This will be more flexible solution for arbitrary formatting.
2022-05-29 Interpolate delayed sample in karplus strong
2022-06-05 Fix initial frequency setting
    [lib.rs]
2022-06-05 Release version 0.5.0
    [Module.kicad_pcb, Module.kicad_sch]
2022-06-19 Be specific about the used frame type
2022-06-26 Increase sample rate to capture oversampling
2022-07-03 Optimize upsampling filter
    No need to multiply coefficients by zeroed values of the signal.
2022-07-03 Optimized decimating filter
2022-07-04 Use the actual sample rate in pd external
2022-07-04 Fix sinc filter coefficients
2022-07-04 Make tape instrument chain more compact
2022-07-05 Add adc to pure data external
2022-07-10 Wire control input from pure data to instruments
2022-07-10 Use 8x oversampling for tape
    16x consumes way too much resources. 8x needs 50 percent less.
    [mod.rs]
2022-07-11 Implement debug for Tape instrument
    This allows dump of the current tape state.
2022-08-09 Place THT on two-layer PCB
    [Module.kicad_pcb, Module.kicad_sch]
2022-08-10 Wire up all connections
    [Module.kicad_pcb, Module.kicad_sch]
2022-08-10 Add extension socket
    It could be hotwired to unused pins of daisy using wires.
    [Module.kicad_pcb, Module.kicad_sch]
2022-08-10 Add S/N silkscreen
    [Module.kicad_pcb]
2022-08-10 Add mouse bites to footprint library
2022-08-10 Connect two panels through mouse bites
    [Module.kicad_pcb]
2022-08-10 Don't keep gerbers under git
2022-08-10 Mark pins without connections
    [Module.kicad_sch]
2022-08-10 Fix all DRC checks
    [Module.kicad_pcb, Module.kicad_sch]
2022-08-11 Fix mousebites
    [Module.kicad_pcb, Module.kicad_sch]
2022-08-11 Assign parts from JLCPCB
    [Module.kicad_pcb]
2022-08-11 Adjust some parts
    [Module.kicad_sch]
2022-08-11 Connect -10V between boards
    [Module.kicad_pcb, Module.kicad_sch]
2022-08-11 Update changelog with recent HW changes
    [Module.kicad_sch]
2022-08-11 Release version 0.6.0
    [Module.kicad_pcb, Module.kicad_sch]
2022-08-11 Replace one of the encoders with a pot
    For better eurorack feel. And one encoder is well enough.
    [display.rs, encoder.rs, firmware.rs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]
2022-08-27 Run embedded encoder test first
2022-08-27 Adjust rotary peripheral to the new encoder
    The new shorter encoder takes only 2 steps for transition.
2022-08-27 Fix embedded test button waiting
    [cv_input.rs, display.rs, encoder.rs]
2022-08-27 Improve encoder testing
2022-08-27 Test gate outputs and document its bugs
    [Module.kicad_sch]
2022-08-27 Introduce stub of Kaseta binding
    [firmware.rs, lib.rs]
2022-08-30 Switch to stable rust and remove primitives
2022-09-12 Fix docstring for cache
    [mod.rs]
2022-10-26 Pin to an official daisy release
2023-09-17 Replace kaseta with a stub of a new module
    [firmware.rs, lib.rs]
2023-09-17 Add logging to track recorder
2023-09-17 track: Implement basic audio passthrough
2023-09-28 Load sample from SD and play it
2023-09-28 Introduce helper function creating sample
2023-09-28 Implement pitch shifting
2023-10-01 Draft of track recorder buffer

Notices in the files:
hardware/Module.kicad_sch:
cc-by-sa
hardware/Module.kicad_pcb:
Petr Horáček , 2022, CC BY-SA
